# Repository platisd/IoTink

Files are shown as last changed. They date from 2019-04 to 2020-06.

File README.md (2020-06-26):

# IoTink
Your portable & connected, e-paper dashboard

IoTink

## What?
**IoT + E-Ink = IoTink**

IoTink is a portable dashboard using an e-paper display and is connected to the
Internet. It is currently utilized to fetch public transport departures and
weather predictions from a
[web service](https://github.com/platisd/vasttrafik-google-assistant) but could
be easily repurposed to accomodate different use cases.

## Why?
IoTink is ideal for times when you need to fetch information via WiFi and display
them on a screen, but it is not feasible to install power cables.

As long as you do not need real-time or frequent updates, IoTink should be
able to remain powered up on 4 AA batteries for a while.

## How?
The concept is rather straightforward, with an ESP8266 microcontroller fetching
data over WiFi and displaying them on the e-paper screen. Then it goes to
deep sleep until it is time to ome back online and fetch updated data.

On a hardware level, things are kept simple, with a minimum ESP8266 circuit that
enables us to program the chip when necessary via UART. 2+2 AA batteries are
supplying just enough voltage for the microcontroller to operate seamlessly.

### Components
* [IoTink PCB rev.0](https://www.pcbway.com/project/shareproject/IoTink__Your_portable_e_paper_dashboard.html)
* [4.2" e-paper module by Waveshare](https://www.waveshare.com/wiki/4.2inch_e-Paper_Module)
* ESP12F
* [4x AA battery holders](https://www.electrokit.com/produkt/batterihallare-1xaa-pcb/) [(Dimensions)](https://i.imgur.com/DCF7JLv.jpg)
* 4x 10KOhm resistors
* 100nF capacitor
* On/Off tactile switch
* 2x 3-pin male headers
* 2x Jumpers
* 6-pin female header
* 8-pin female header

### Software dependencies
* [GxEPD](https://github.com/ZinggJM/GxEPD/) library for controlling the e-paper display
* [Adafruit GFX](https://github.com/adafruit/Adafruit-GFX-Library) library for the graphics
* [ArduinoJson](https://github.com/bblanchon/ArduinoJson) library for parsing JSON

## Media
* [Background story](https://platis.solutions/blog/2019/02/18/iotink-your-portable-e-paper-dashboard/)
* [Demo video](https://youtu.be/FovcpUYtC_o)

## License
The IoTink project is released under a dual licensing scheme, because we
are obligated to use a copyleft license for the software.

### Software
**GPLv3** - The license had to be selected due to depending on GPL'd software,
i.e. the [GxEPD](https://github.com/ZinggJM/GxEPD/) library. Pull requests that
will enable this project adopt a more permissive license are more than welcome.

### Hardware
**CC-BY 4.0**

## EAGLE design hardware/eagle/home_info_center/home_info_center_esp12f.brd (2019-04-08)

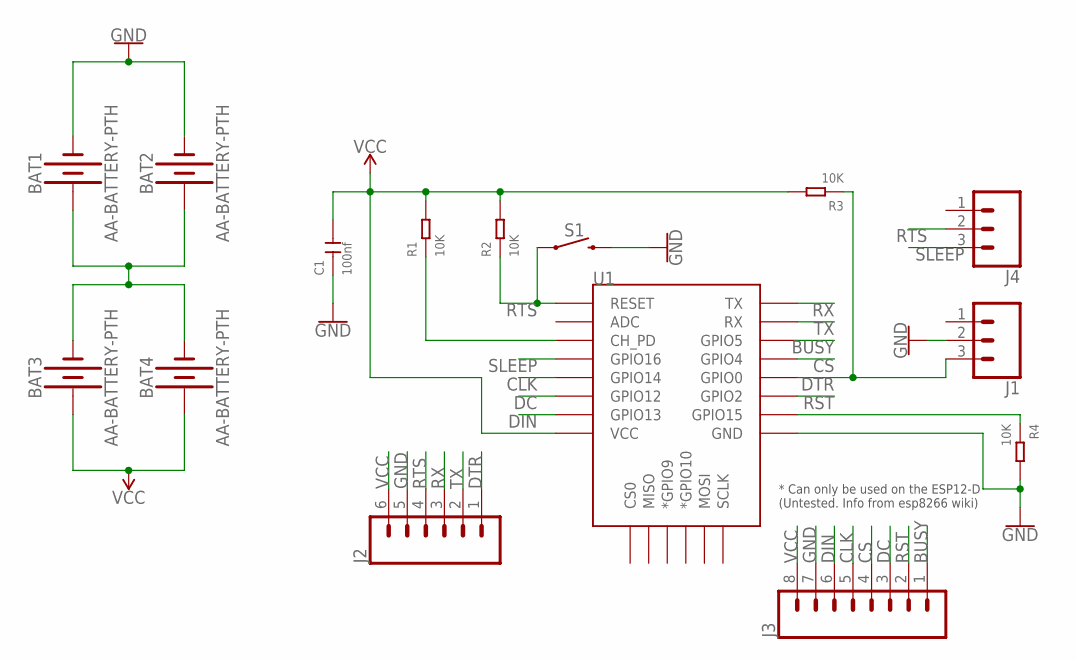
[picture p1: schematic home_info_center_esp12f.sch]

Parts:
BAT1, BAT2, BAT3, BAT4: AA-BATTERY-PTH; AA-PCB-BATTERY
C1: 100nf; CERAMIC-2.54
J1, J4: CONN_03; 1X03
J2: CONN_06LOCK; 1X06_LOCK
J3: CONN_08LOCK; 1X08_LOCK
R1, R2, R3, R4: 10K; PR-D2.3XL6.5MM
S1: MOMENTARY-SWITCH-SPST-PTH-6.0MM-KIT; TACTILE_SWITCH_PTH_6.0MM_KIT
U1: ESP12ESMD; ESP12E-SMD

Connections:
BUSY: J3.1, U1.GPIO5
CLK: J3.5, U1.GPIO14
CS: J3.4, U1.GPIO4
DC: J3.3, U1.GPIO12
DIN: J3.6, U1.GPIO13
DTR: J1.3, J2.1, R3.1, U1.GPIO0
GND: BAT1.NEG (-), BAT2.NEG (-), C1.1, J1.2, J2.5, J3.7, R4.2, S1.3 (2), U1.GND
unnamed: R1.1, U1.CH_PD
unnamed: R4.1, U1.GPIO15
unnamed: BAT1.POS (+), BAT2.POS (+), BAT3.NEG (-), BAT4.NEG (-)
RST: J3.2, U1.GPIO2
RTS: J2.4, J4.2, R2.1, S1.1, U1.RESET
RX: J2.3, U1.TXD0 (TX)
SLEEP: J4.3, U1.GPIO16
TX: J2.2, U1.RXD0 (RX)
VCC: BAT3.POS (+), BAT4.POS (+), C1.2, J2.6, J3.8, R1.2, R2.2, R3.2, U1.VCC

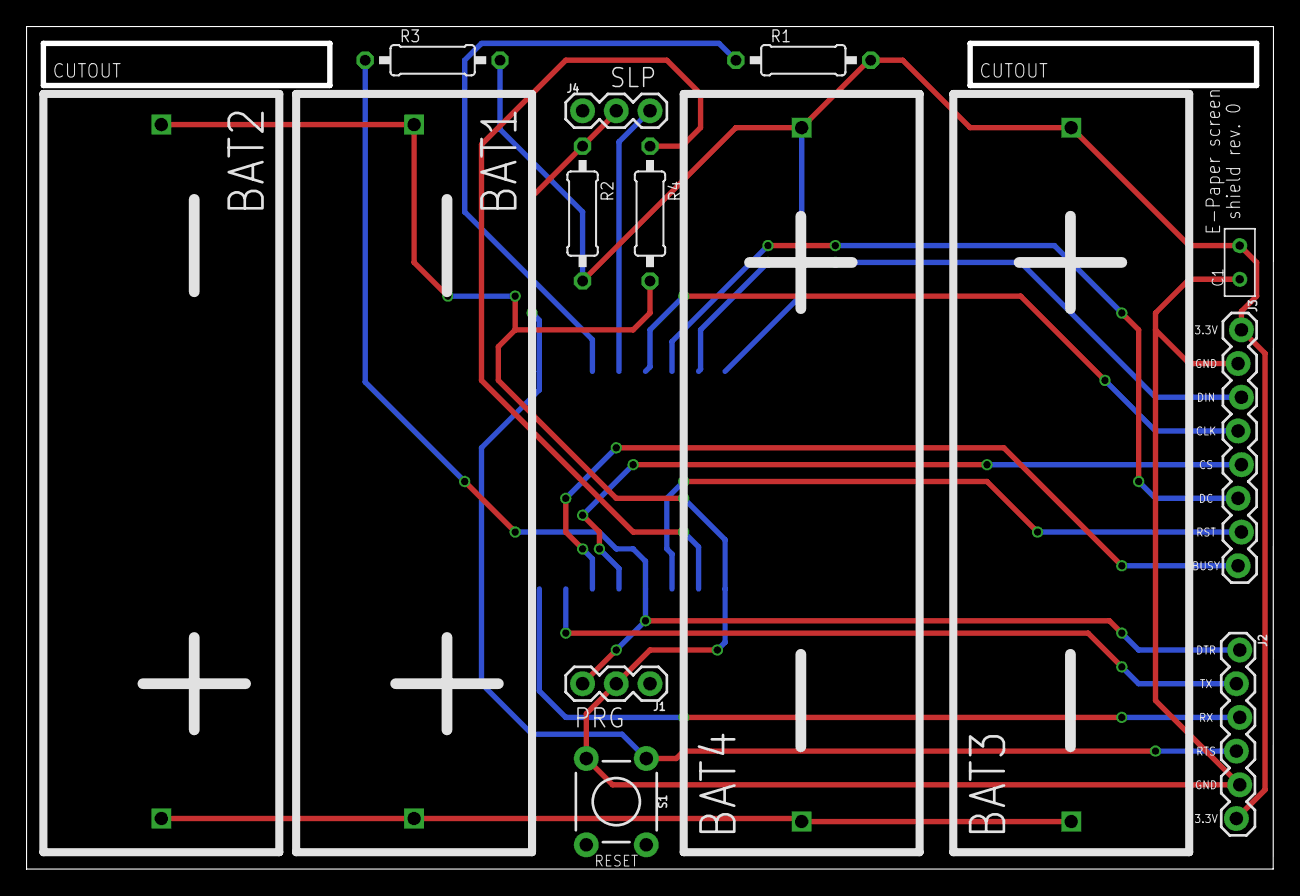
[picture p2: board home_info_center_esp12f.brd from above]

Board: 2 copper layers, 94.0 x 63.5 mm, 15 parts (1 on the bottom side), 16 nets.

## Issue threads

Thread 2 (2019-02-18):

Add on/off switch

platisd, 2019-02-18:
As an Iotink user I would like to be able to completely turn the power off on the board when I leave for vacation so the batteries don't get needlessly depleted.

Acceptance criteria:
* Readily available and cheap on/off switch is added.

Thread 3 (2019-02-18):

Add a Low Dropout (LDO) Regulator

platisd, 2019-02-18:
As an Iotink user I would like to have the microcontroller and the screen powered consistently regardless of the voltage drop of the batteries so I can be sure that Iotink will operate consistently.

Acceptance criteria:
* LDO is added (preferably the MCP1700-3302E in a SOT54 package) to regulate the power from the batteries.

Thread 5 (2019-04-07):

some questions to get this nice and great iotink

phototobi, 2019-04-07:
Hi,
since i´ve seen your great iotink project, i like to fork it and build my own Display for our kids school bus timer. Quiet often they are that late missing their bus getting to school in time. I´ve already worked on grabbing the times from the webite of our local busservice with my beloved node-red running on my pi.

So i will to understand your code implent my mqtt broker and getting the topics for the two buslines and the times. For the weatherforcecast i would like to stay on your solution, as i already grab openweather data with node red using this api key.
Maybe i´m wrong but it seems your are  using the api key which comes out of a file? I´ve already made a free pythonanywhere account to get it running. Would it be possible to run the python script on my pi, simmilar to other python sripts which are running on it by edtitng the link of the credentials.h Otherwhise i ´ll  try to understand how this pythonanaywhere works. It seems you are unsing not the beginners account. Does it make any difference with a beginner a.

Many thanks in advance. I hope i can make it, i´m still newbie with Arduino and this stuff but it´s wonderfull getting things running,sometimes with a little help from pro´s like you.

Tobias, from Königswinter, Germany

platisd, 2019-04-07:
> Maybe i´m wrong but it seems your are using the api key which comes out of a file? I´ve already made a free pythonanywhere account to get it running. Would it be possible to run the python script on my pi, simmilar to other python sripts which are running on it by edtitng the link of the credentials.h Otherwhise i ´ll try to understand how this pythonanaywhere works. It seems you are unsing not the beginners account. Does it make any difference with a beginner a.

Hi Tobias! Thanks for contacting me.
I am not sure if I have understood what you mean entirely, but yes, the python script would be able to run anywhere, even in your own Raspberry Pi. I am reading the API key from a file because I don't want to version control it and accidentally commit it, but if you don't care about pushing your stuff on a public repository then you can simply place the key within your code. That is also the point with `credentials.h`. All the "secret" stuff I place in a header file ignored by git so I don't commit them.

On pythonanywhere.com I have a free account since both the weather website as well as the local public transport company are [whitelisted](https://www.pythonanywhere.com/whitelist/) and therefore can be accessed without the need for a premium account.

Not sure if I have answered your question, if not, please let me know!

phototobi, 2019-04-08:
Hi thanks for your help. I´ve tried to understand foldername and filename for the api keyfile. Is there another "secret" header file? Can you send me a bulkfile how it should look like. Also for the api key(Is it just txt with key in plaintext? And where do you place the loaction for openweathermap to forcast it.
Thanx in advance

phototobi, 2019-04-08:
Another question? Is http://platisd.pythonanywhere.com/info-center-data  a pythonanywhere web app. How does this work to place the forecast on this /info-center-data url

platisd, 2019-04-12:
I updated your comment a bit because I had mistakenly committed a file that I shouldn't have. :stuck_out_tongue:

In any case, I'd suggest you figuring out how hosting a python web server works on `pythonanywhere` and then working out the rest. Generally there isn't anything "special" done. It is a Python3 script that uses Flask.

The `secret` file merely contains the API keys in new lines. Nothing fancy at all. You can include them in your script instead, meaning that you don't necessarily have to have a "secret" file that has the keys.

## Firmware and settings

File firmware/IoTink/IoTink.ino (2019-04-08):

#include <GxEPD.h>
#include <GxGDEW042T2/GxGDEW042T2.h>
#include <Fonts/FreeMonoBold9pt7b.h>
#include <Fonts/FreeMonoBold12pt7b.h>
#include <Fonts/FreeMonoBold24pt7b.h>
#include <GxIO/GxIO_SPI/GxIO_SPI.h>
#include <GxIO/GxIO.h>

#include <ESP8266WiFi.h>
#include <ESP8266HTTPClient.h>
#include <ArduinoJson.h>

// Keep your project specific credentials in a non-version controlled
// `credentials.h` file and set the `NO_CREDENTIALS_HEADER` to false.
#define NO_CREDENTIALS_HEADER false
#if NO_CREDENTIALS_HEADER == true
const auto kInternetSSID = "your-ssid";
const auto kWifiPassword = "your-wifi-password";
const auto kServerUrl = "http://url.com/for/your/server";
#else
#include "credentials.h"
#endif

const int kScreenWidth = 400;
const int kScreenHeight = 300;
const int kFont24ptInPixelsHeight = 32;
const int kFont18ptInPixelsHeight = 24;
const int kFont12ptInPixelsHeight = 16;
const int kFont9ptInPixelsHeight = 12;
const int kHeightCursorOffset = 30;

const int kTopTimeLengthInPixels = 142;
const int kTopRectangleWidth = kScreenWidth;
const int kTopRectangleHeight = kScreenHeight / 6;
const int kTopTimeCursorX = (kScreenWidth - kTopTimeLengthInPixels) / 2;
const int kTopTimeCursorY = kHeightCursorOffset + (kTopRectangleHeight - kFont24ptInPixelsHeight) / 2;

const int kMiddleDividerWidth = 5;
const int kMiddleDividerCursorY = kTopRectangleHeight;
const int kMiddleDividerCursorX = (kScreenWidth - kMiddleDividerWidth) / 2;
const int kMiddleAreaHeight = 3.5 * kTopRectangleHeight;

const int kVarbergsgatanWidth = 182;
const int kFredasgatanWidth = 154;
const int kVarbergsgatanPadding = (kMiddleDividerCursorX - kVarbergsgatanWidth) / 2;
const int kFredasgatanPadding = (kMiddleDividerCursorX - kFredasgatanWidth) / 2;
const int kVarbergsgatanCursorX = kVarbergsgatanPadding;
const int kFredasgatanCursorX = kMiddleDividerCursorX + kMiddleDividerWidth + kFredasgatanPadding;
const int kStationNameCursorY = kTopRectangleHeight + kFont12ptInPixelsHeight * 1.3;
const int kStationNameDividerCursorY = kStationNameCursorY + kFont12ptInPixelsHeight * 0.7;

const int kNextDepartureLabelCursorY = kStationNameDividerCursorY + kFont9ptInPixelsHeight * 1.3;
const int kNextDepartureMinutesCursorY = kNextDepartureLabelCursorY + kFont24ptInPixelsHeight * 3;
const int kNextDepartureVarbergsgatanCursorX = kVarbergsgatanCursorX - 10;
const int kNextDepartureFredasgatanCursorX = kFredasgatanCursorX - 10;
const int kLaterDepartureMinutesCursorY = kNextDepartureMinutesCursorY + kFont12ptInPixelsHeight * 1.6;
const int kLaterDeparturesRightPadding = 30;
const int kLaterVarbergsgatanDeparturesCursorX = kMiddleDividerCursorX - kLaterDeparturesRightPadding;
const int kLaterFredasgatanDeparturesCursorX = kScreenWidth - kLaterDeparturesRightPadding;

const int kBottomRectangleHeight = kScreenHeight - kMiddleAreaHeight - kTopRectangleHeight;
const int kBottomDividerCursorY = kTopRectangleHeight + kMiddleAreaHeight;
const int kBottomDividerHeight = kMiddleDividerWidth;
const int kBottomBoxCursorY = kBottomDividerCursorY + kBottomDividerHeight;
const int kBottomBoxWidth = kScreenWidth / 4;

const int kTemperatureCursorY = kBottomDividerCursorY + kMiddleDividerWidth + kFont12ptInPixelsHeight * 1.2;
const int kDegreesCursorY = kTemperatureCursorY - kFont12ptInPixelsHeight * 0.5;
const char* kDegreesSymbol = "o";

const int kWeatherCursorY = kTemperatureCursorY + kFont12ptInPixelsHeight * 1.4;
const int kWeatherTimeCursorY = kWeatherCursorY + kFont12ptInPixelsHeight * 1.4;
const int kWeatherPadding = 1;

const unsigned long kRequestTimeout = 15000UL; // In milliseconds
const unsigned long kNormalDeepSleepDuration = 60e6; // In microseconds
const unsigned long kErrorDeepSleepDuration = kNormalDeepSleepDuration / 4; // In microseconds
const unsigned long kLongDeepSleepDuration = kNormalDeepSleepDuration * 60; // In microseconds

GxIO_Class io(SPI, /*CS=D8*/ 4, /*DC=D6*/ 12, /*RST=D4*/ 2);
GxEPD_Class display(io, /*RST=D4*/ 2, /*BUSY=D2*/ 5);

unsigned long timeOfTheDayToSleepInterval(const char* timeOfDay) {
  // Verify we actually received an input in the format HH:mm
  if (timeOfDay == nullptr || timeOfDay[0] == '\0' || timeOfDay[1] == '\0') {
    return kNormalDeepSleepDuration;
  }
  const char timeBuffer[] = {timeOfDay[0], timeOfDay[1]};
  const auto currentHour = atoi(timeBuffer);

  // If it's night or too early in the morning, there's no need for updates
  if (currentHour > 22 || currentHour < 7) {
    return kLongDeepSleepDuration;
  }

  return kNormalDeepSleepDuration;
}

void draw(const char* updateTime,
          const char* nextVarbergsgatanDeparture, const char* laterVarbergsgatanDeparture,
          const char* nextFredasgatanDeparture, const char* laterFredasgatanDeparture,
          const char* recentPredictionTime, const char* recentWeather, int recentTemperature,
          const char* shortRangePredictionTime, const char* shortRangePredictionWeather, int shortRangePredictionTemperature,
          const char* midRangePredictionTime, const char* midRangePredictionWeather, int midRangePredictionTemperature,
          const char* longRangePredictionTime, const char* longRangePredictionWeather, int longRangePredictionTemperature) {

  display.init();
  pinMode(12, OUTPUT); // Pin 12 on ESP8266 is initialized as input by SPI so we must set it as OUTPUT again
  display.fillScreen(GxEPD_WHITE);


  display.fillRect(0, 0, kTopRectangleWidth, kTopRectangleHeight, GxEPD_BLACK);
  display.setFont(&FreeMonoBold24pt7b);
  display.setTextColor(GxEPD_WHITE);
  display.setCursor(kTopTimeCursorX, kTopTimeCursorY); // w: (400 - 140) / 2 -- h: 30 + (60 - 32) / 2
  display.print(updateTime);

  display.setFont(&FreeMonoBold12pt7b);
  display.setTextColor(GxEPD_BLACK);
  display.setCursor(kVarbergsgatanCursorX, kStationNameCursorY);
  display.print("Varbergsgatan");
  display.setCursor(kFredasgatanCursorX, kStationNameCursorY);
  display.print("Fredasgatan");

  display.drawFastHLine(0, kStationNameDividerCursorY, kScreenWidth, GxEPD_BLACK);

  display.setFont(&FreeMonoBold9pt7b);
  display.setCursor(kVarbergsgatanCursorX, kNextDepartureLabelCursorY);
  display.print("Next trams:");
  display.setCursor(kFredasgatanCursorX, kNextDepartureLabelCursorY);
  display.print("Next buses:");

  display.setFont(&FreeMonoBold24pt7b);
  display.setTextSize(3);
  display.setCursor(kNextDepartureVarbergsgatanCursorX, kNextDepartureMinutesCursorY);
  display.print(nextVarbergsgatanDeparture);
  display.setCursor(kNextDepartureFredasgatanCursorX, kNextDepartureMinutesCursorY);
  display.print(nextFredasgatanDeparture);

  display.setFont(&FreeMonoBold12pt7b);
  display.setTextSize(1);
  display.setCursor(kLaterVarbergsgatanDeparturesCursorX, kLaterDepartureMinutesCursorY);
  display.print(laterVarbergsgatanDeparture);
  display.setCursor(kLaterFredasgatanDeparturesCursorX, kLaterDepartureMinutesCursorY);
  display.print(laterFredasgatanDeparture);

  display.fillRect(kMiddleDividerCursorX, kMiddleDividerCursorY, kMiddleDividerWidth, kMiddleAreaHeight, GxEPD_BLACK);
  display.fillRect(0, kBottomDividerCursorY, kScreenWidth, kBottomDividerHeight, GxEPD_BLACK);

  display.fillRect(0, kBottomBoxCursorY, kBottomBoxWidth, kBottomRectangleHeight, GxEPD_BLACK);
  display.fillRect(kScreenWidth / 2, kBottomBoxCursorY, kBottomBoxWidth, kBottomRectangleHeight, GxEPD_BLACK);

  // Most recent weather data
  display.setCursor(0, kTemperatureCursorY);
  display.setTextColor(GxEPD_WHITE);
  display.print(recentTemperature);
  display.setFont(&FreeMonoBold9pt7b);
  display.setCursor(display.getCursorX(), kDegreesCursorY);
  display.print(kDegreesSymbol);

  display.setFont(&FreeMonoBold12pt7b);
  display.setCursor(kWeatherPadding, kWeatherCursorY);
  display.print(recentWeather);
  display.setCursor(0, kWeatherTimeCursorY);
  display.print(recentPredictionTime);

  // Next prediction weather data
  display.setCursor(kWeatherPadding + kBottomBoxWidth, kTemperatureCursorY);
  display.setTextColor(GxEPD_BLACK);
  display.print(shortRangePredictionTemperature);
  display.setFont(&FreeMonoBold9pt7b);
  display.setCursor(display.getCursorX(), kDegreesCursorY);
  display.print(kDegreesSymbol);

  display.setFont(&FreeMonoBold12pt7b);
  display.setCursor(kWeatherPadding + kBottomBoxWidth, kWeatherCursorY);
  display.print(shortRangePredictionWeather);

  display.setCursor(kWeatherPadding + kBottomBoxWidth, kWeatherTimeCursorY);
  display.print(shortRangePredictionTime);

  // Mid prediction weather data
  display.setCursor(kWeatherPadding + 2 * kBottomBoxWidth, kTemperatureCursorY);
  display.setTextColor(GxEPD_WHITE);
  display.print(midRangePredictionTemperature);
  display.setFont(&FreeMonoBold9pt7b);
  display.setCursor(display.getCursorX(), kDegreesCursorY);
  display.print(kDegreesSymbol);

  display.setFont(&FreeMonoBold12pt7b);
  display.setCursor(kWeatherPadding + 2 * kBottomBoxWidth, kWeatherCursorY);
  display.print(midRangePredictionWeather);

  display.setCursor(kWeatherPadding + 2 * kBottomBoxWidth, kWeatherTimeCursorY);
  display.print(midRangePredictionTime);

  // Far prediction weather data
  display.setCursor(kWeatherPadding + 3 * kBottomBoxWidth, kTemperatureCursorY);
  display.setTextColor(GxEPD_BLACK);
  display.print(longRangePredictionTemperature);
  display.setFont(&FreeMonoBold9pt7b);
  display.setCursor(display.getCursorX(), kDegreesCursorY);
  display.print(kDegreesSymbol);

  display.setFont(&FreeMonoBold12pt7b);
  display.setCursor(kWeatherPadding + 3 * kBottomBoxWidth, kWeatherCursorY);
  display.print(longRangePredictionWeather);

  display.setCursor(kWeatherPadding + 3 * kBottomBoxWidth, kWeatherTimeCursorY);
  display.print(longRangePredictionTime);

  display.update();
}

/**
   (Re)connects the module to WiFi

   @return true if connection was succesful otherwise false
*/
bool connectToWifi() {
  // Set WiFi to station mode & disconnect from an AP if previously connected
  WiFi.mode(WIFI_STA);
  WiFi.disconnect();

  // Try to connect to the internet
  WiFi.begin(kInternetSSID, kWifiPassword);
  auto attemptsLeft = 1000;
  while ((WiFi.status() != WL_CONNECTED) && (--attemptsLeft > 0)) {
    delay(10); // Wait a bit before retrying
  }
  return attemptsLeft > 0;
}

void setup()
{
  if (!connectToWifi()) {
    ESP.deepSleep(kErrorDeepSleepDuration);
    return;
  }

  HTTPClient http;
  http.setTimeout(kRequestTimeout);
  http.begin(kServerUrl);
  auto httpCode = http.GET();

  if (httpCode < 0 || httpCode != HTTP_CODE_OK) {
    http.end();
    ESP.deepSleep(kErrorDeepSleepDuration);
    return;
  }

  DynamicJsonDocument doc(600);
  deserializeJson(doc, http.getStream());
  JsonObject root = doc.as<JsonObject>();

  JsonArray predictions = root["pred"];
  JsonArray recentPredictions = predictions[0];
  JsonArray shortRangePredictions = predictions[1];
  JsonArray midRangePredictions = predictions[2];
  JsonArray longRangePredictions = predictions[3];

  draw(root["time"].as<const char*>(),
       root["depsA"][0].as<const char*>(), root["depsA"][1].as<const char*>(),
       root["depsB"][0].as<const char*>(), root["depsB"][1].as<const char*>(),
       recentPredictions[0].as<const char*>(), recentPredictions[1].as<const char*>(), recentPredictions[2].as<int>(),
       shortRangePredictions[0].as<const char*>(), shortRangePredictions[1].as<const char*>(), shortRangePredictions[2].as<int>(),
       midRangePredictions[0].as<const char*>(), midRangePredictions[1].as<const char*>(), midRangePredictions[2].as<int>(),
       longRangePredictions[0].as<const char*>(), longRangePredictions[1].as<const char*>(), longRangePredictions[2].as<int>());

  ESP.deepSleep(timeOfTheDayToSleepInterval(root["time"].as<const char*>()));
}

void loop()
{
  // We should never be here, but just in case this ever happens, go to sleep
  ESP.deepSleep(kErrorDeepSleepDuration);
}

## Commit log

2019-04-08 Add IoTink Arduino sketch
2019-04-08 Add rev.0 PCB design
    TODO for rev.1:
    * Move BAT4 to the right so to be evenly spaced
    * Add ON/OFF switch
    * Add MCP1700-3302E LDO
    [home_info_center_esp12f.brd, home_info_center_esp12f.sch]
2019-04-08 Add link to purchase from PCBWay
2019-04-08 Add forgotten dependency to ArduinoJSON
2019-04-08 Sleep longer in the night
    In order to consume less power, sleep for about an hour
    during the night when no one is probably using the IoTink
2019-04-08 Decrease execution time
    * Remove serial print outs
    * Increase long sleep time during the night
    * Remove unused method

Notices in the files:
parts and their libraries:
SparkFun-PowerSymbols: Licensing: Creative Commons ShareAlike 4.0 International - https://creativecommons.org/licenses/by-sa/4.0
